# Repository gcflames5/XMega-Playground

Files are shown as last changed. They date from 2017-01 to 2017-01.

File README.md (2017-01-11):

XMega Playground
====

Overview
----
This board serves as a place where users can practice various aspects of embedded programming using an XMega(128/64/32)A4U. The first version of this board is focused heavily on testing various types of communication protocols, featuring USB, Serial, CAN, SPI, and I2C. Additionally, the board includes a pair of 7 segment displays, and 10 LEDs (4 are digital RGB LEDs) to allow a degree of output to the user. For use with these various communication protocols, this board includes an separate ADC (with pressure and temperature sensors), flash memory IC, TTL to RS-232 level shifter, CAN transciever, and two IMUs.



List of Features (version 1.0)
----
 - 2 7-segment displays (driven by shift registers)
 - 4 WS2812B digital RHB leds
 - 6 0805 LEDs
 - CAN Transciever
 - RS-232 to TTL level shifter
 - 2 IMUs: Acceleration, Magetometer
 - ADC (w/ 2.5V reference chip)
   - Temperature sensor
   - Ambient pressure sensor
 - Flash Memory
 - Current Sense Op Amp
   - Configurable load for testing

Considerations for Future Versions
----
 - Add a character LCD display for more useful output to the user
 - Break out more GPIO pins into headers
 - Expand number of 7 segment displays
 - Utilize DAC and waveform generation, include H-bridge, microphone, speaker, etc.

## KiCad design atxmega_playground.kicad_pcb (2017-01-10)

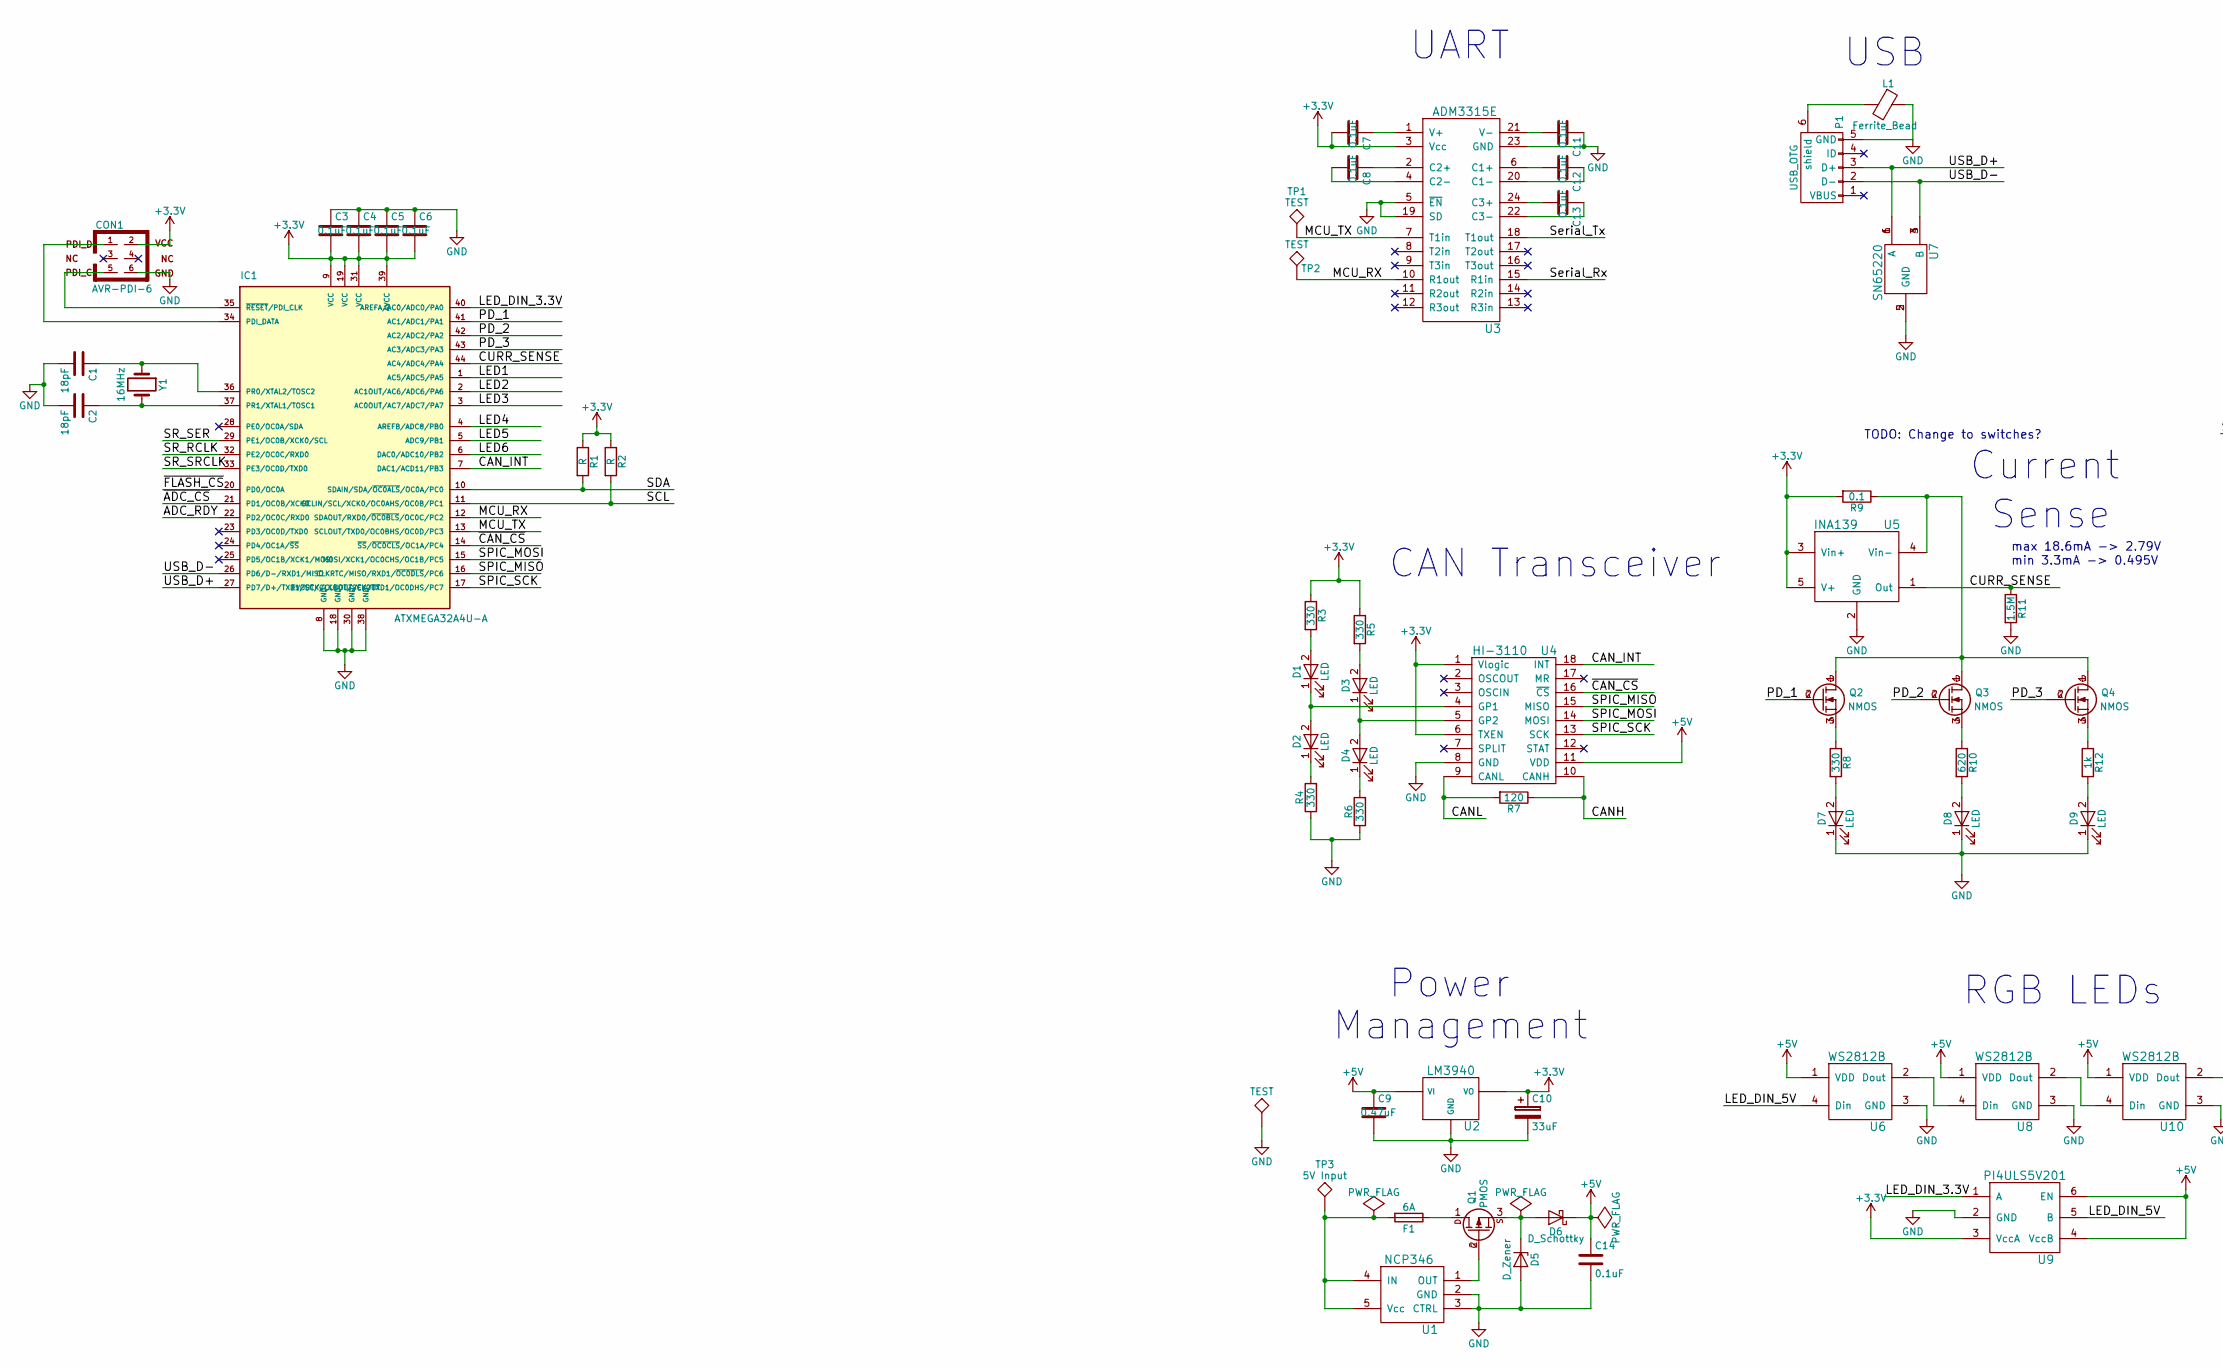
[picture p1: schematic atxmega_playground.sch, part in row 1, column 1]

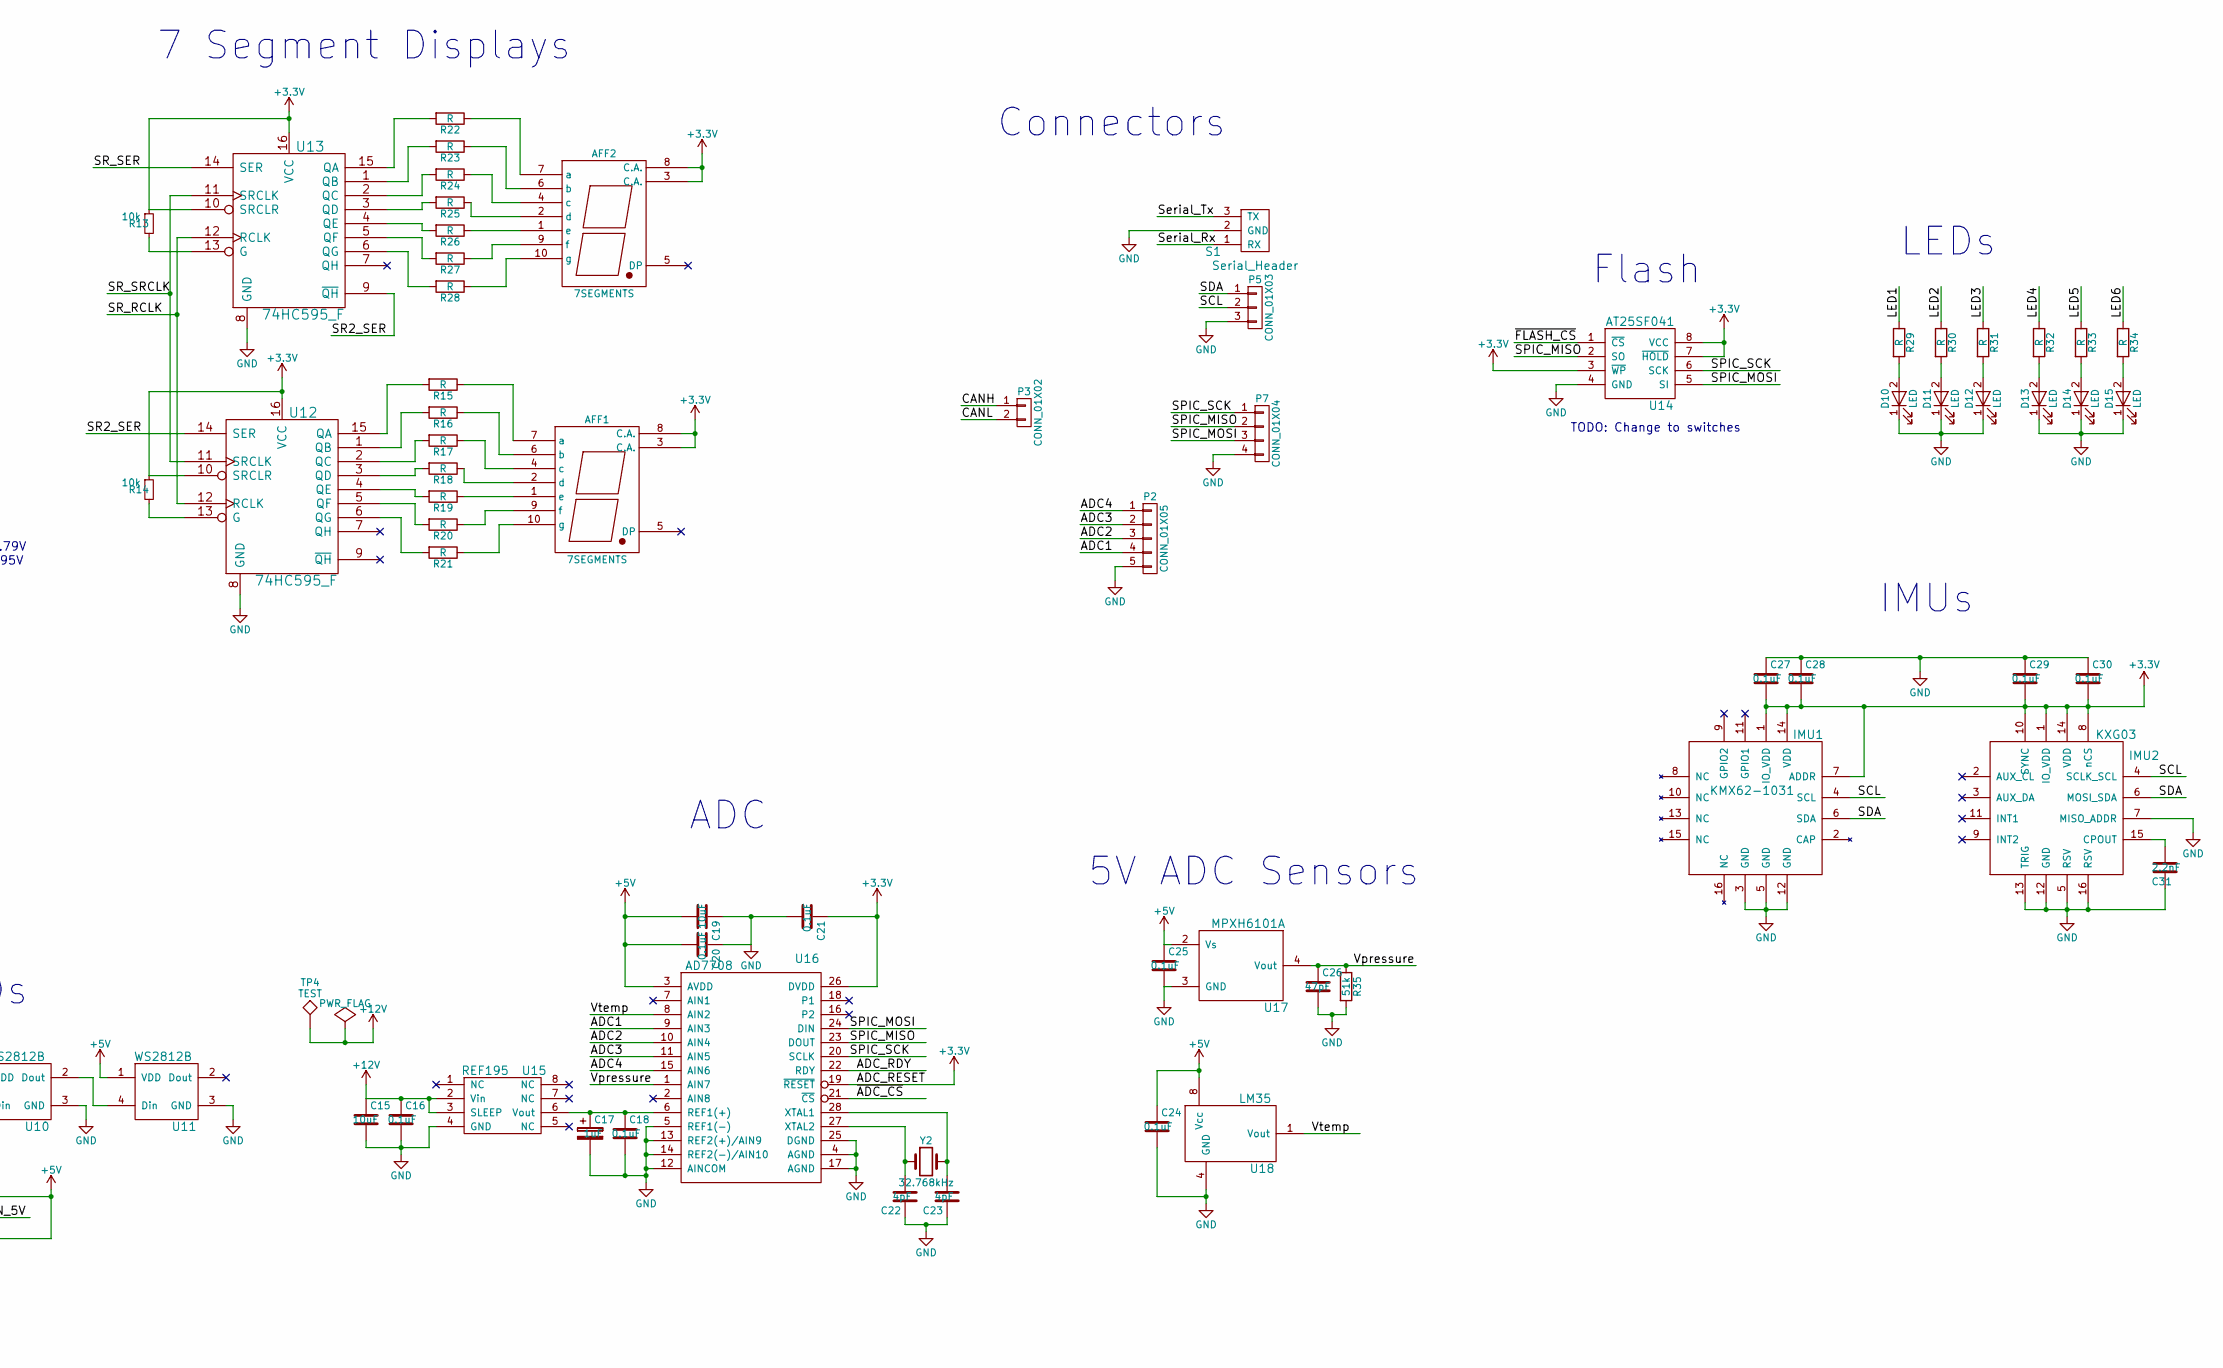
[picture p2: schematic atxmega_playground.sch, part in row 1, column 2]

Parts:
AFF1, AFF2: 7SEGMENTS; 7seg_SC56-11SRWA
C1, C2: 18pF; C_0805
C3, C4, C5, C6, C7, C8, C11, C12, C13, C14, C16, C18, C20, C21, C24, C25, C27, C28, C29, C30: 0.1uF; C_0805
C9: 0.47uF; C_0805
C10: 33uF; R_1206
C15, C19: 10uF; C_0805
C17: 1uF; R_1206
C22, C23: 4pF; C_0805
C26: 47pF; C_0805
C31: 2.2nF; C_0805
CON1: AVR-PDI-6; Pin_Header_Straight_2x03_Pitch2.54mm
D1, D2, D3, D4, D7, D8, D9, D10, D11, D12, D13, D14, D15: LED; LED_0805
D5: D_Zener; SOD-123
D6: D_Schottky; R_0805
F1: 6A; R_1206
IC1: ATXMEGA32A4U-A; TQFP-44_10x10mm_Pitch0.8mm
IMU1: KMX62-1031; KXG03_footprint
IMU2: KXG03; KXG03_footprint
L1: Ferrite_Bead; R_0805
P1: USB_OTG; USB_Mini-B
P2: CONN_01X05; Pin_Header_Straight_1x05_Pitch2.54mm
P3: CONN_01X02; Pin_Header_Straight_1x02_Pitch2.54mm
P5: CONN_01X03; Pin_Header_Straight_1x03_Pitch2.54mm
P7: CONN_01X04; Pin_Header_Straight_1x04_Pitch2.54mm
Q1: PMOS; SOT-23-3_Handsoldering
Q2, Q3, Q4: NMOS; SOT-23-3_Handsoldering
R1, R2, R15, R16, R17, R18, R19, R20, R21, R22, R23, R24, R25, R26, R27, R28, R29, R30, R31, R32, R33, R34: R; R_0805
R3, R4, R5, R6, R8: 330; R_0805
R7: 120; R_0805
R9: 0.1; R_0805
R10: 620; R_0805
R11: 1.5M; R_0805
R12: 1k; R_0805
R13, R14: 10k; R_0805
R35: 51k; R_0805
S1: Serial_Header; Pin_Header_Straight_1x03_Pitch2.54mm
TP1, TP2, TP4, TP5: TEST; TESTPOINT
TP3: 5V Input; TESTPOINT
U1: NCP346; SOT-23-5
U2: LM3940; SOT-223
U3: ADM3315E; TSSOP-24_4.4x7.8mm_Pitch0.65mm
U4: HI-3110; SOIC-18W_7.5x11.6mm_Pitch1.27mm
U5: INA139; SOT-23-5
U6, U8, U10, U11: WS2812B
U7: SN65220; SOT-23-6
U9: PI4ULS5V201; SOT-23-6
U12, U13: 74HC595_F; SOIC-16_3.9x9.9mm_Pitch1.27mm
U14: AT25SF041; SOIC-8_3.9x4.9mm_Pitch1.27mm
U15: REF195; SOIC-8_3.9x4.9mm_Pitch1.27mm
U16: AD7708; SOIC-28W_7.5x17.9mm_Pitch1.27mm
U17: MPXH6101A; SOIC-8_7.5x7.5mm_Pitch1.27mm
U18: LM35; SOIC-8_3.9x4.9mm_Pitch1.27mm
Y1: 16MHz; Crystal_HC49-U_Vertical
Y2: 32.768kHz; R_0805

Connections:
+3V3: AFF1.3 (C.A.), AFF1.8 (C.A.), AFF2.3 (C.A.), AFF2.8 (C.A.), C3.2, C4.2, C5.2, C6.2, C7.2, C10.1, C21.1, C27.2, C28.2, C29.2, C30.2, CON1.2, IC1.9 (VCC), IC1.19 (VCC), IC1.31 (VCC), IC1.39 (AVCC), IMU1.1 (IO_VDD), IMU1.7 (ADDR), IMU1.14 (VDD), IMU2.1 (IO_VDD), IMU2.8 (nCS), IMU2.10 (SYNC), IMU2.14 (VDD), R1.1, R2.1, R3.1, R5.1, R9.2, R13.1, R14.1, U2.3 (VO), U3.3 (Vcc), U4.1 (Vlogic), U4.6 (TXEN), U5.3 (Vin+), U5.5 (V+), U9.3 (VccA), U12.10 (SRCLR), U12.16 (VCC), U13.10 (SRCLR), U13.16 (VCC), U14.3 (~WP), U14.7 (~HOLD), U14.8 (VCC), U16.19 (~RESET), U16.26 (DVDD)
+5V: C9.1, C14.1, C19.2, C20.2, C24.1, C25.1, D6.1 (K), U2.1 (VI), U4.11 (VDD), U6.1 (VDD), U8.1 (VDD), U9.4 (VccB), U9.6 (EN), U10.1 (VDD), U11.1 (VDD), U16.3 (AVDD), U17.2 (Vs), U18.8 (Vcc)
+12V: C15.1, C16.1, TP4.1, U15.2 (Vin), U15.3 (SLEEP)
/ADC1: P2.4, U16.9 (AIN3)
/ADC2: P2.3, U16.10 (AIN4)
/ADC3: P2.2, U16.11 (AIN5)
/ADC4: P2.1, U16.15 (AIN6)
/ADC_RDY: IC1.22 (PD2/OC0C/RXD0), U16.22 (RDY)
/CANH: P3.1, R7.1, U4.10 (CANH)
/CANL: P3.2, R7.2, U4.9 (CANL)
/CAN_INT: IC1.7 (DAC1/ACD11/PB3), U4.18 (INT)
/CURR_SENSE: IC1.44 (AC4/ADC4/PA4), R11.1, U5.1 (Out)
/LED1: IC1.1 (AC5/ADC5/PA5), R29.1
/LED2: IC1.2 (AC1OUT/AC6/ADC6/PA6), R30.1
/LED3: IC1.3 (AC0OUT/AC7/ADC7/PA7), R31.1
/LED4: IC1.4 (AREFB/ADC8/PB0), R32.1
/LED5: IC1.5 (ADC9/PB1), R33.1
/LED6: IC1.6 (DAC0/ADC10/PB2), R34.1
/LED_DIN_3.3V: IC1.40 (AREFA/AC0/ADC0/PA0), U9.1 (A)
/LED_DIN_5V: U6.4 (Din), U9.5 (B)
/MCU_RX: IC1.12 (SDAOUT/RXD0/~OC0BLS~/OC0C/PC2), TP2.1, U3.10 (R1out)
/MCU_TX: IC1.13 (SCLOUT/TXD0/OC0BHS/OC0D/PC3), TP1.1, U3.7 (T1in)
/PD_1: IC1.41 (AC1/ADC1/PA1), Q2.2 (G)
/PD_2: IC1.42 (AC2/ADC2/PA2), Q3.2 (G)
/PD_3: IC1.43 (AC3/ADC3/PA3), Q4.2 (G)
/SCL: IC1.11 (SCLIN/SCL/XCK0/OC0AHS/OC0B/PC1), IMU1.4 (SCL), IMU2.4 (SCLK_SCL), P5.2, R2.2
/SDA: IC1.10 (SDAIN/SDA/~OC0ALS~/OC0A/PC0), IMU1.6 (SDA), IMU2.6 (MOSI_SDA), P5.1, R1.2
/SPIC_MISO: IC1.16 (CLKRTC/MISO/RXD1/~OC0DLS~/PC6), P7.2, U4.15 (MISO), U14.2 (SO), U16.23 (DOUT)
/SPIC_MOSI: IC1.15 (MOSI/XCK1/OC0CHS/OC1B/PC5), P7.3, U4.14 (MOSI), U14.5 (SI), U16.24 (DIN)
/SPIC_SCK: IC1.17 (EVOUT/CLKOUT/SCK/TXD1/OC0DHS/PC7), P7.1, U4.13 (SCK), U14.6 (SCK), U16.20 (SCLK)
/SR2_SER: U12.14 (SER), U13.9 (~QH)
/SR_RCLK: IC1.32 (PE2/OC0C/RXD0), U12.12 (RCLK), U13.12 (RCLK)
/SR_SER: IC1.29 (PE1/OC0B/XCK0/SCL), U13.14 (SER)
/SR_SRCLK: IC1.33 (PE3/OC0D/TXD0), U12.11 (SRCLK), U13.11 (SRCLK)
/Serial_Rx: S1.1 (RX), U3.15 (R1in)
/Serial_Tx: S1.3 (TX), U3.18 (T1out)
/USB_D+: IC1.27 (PD7/D+/TXD1/SCK/CLKOUT/EVOUT), P1.3 (D+), U7.1 (A), U7.6 (A)
/USB_D-: IC1.26 (PD6/D-/RXD1/MISO), P1.2 (D-), U7.3 (B), U7.4 (B)
/Vpressure: C26.1, R35.1, U16.1 (AIN7), U17.4 (Vout)
/Vtemp: U16.8 (AIN2), U18.1 (Vout)
/~ADC_CS: IC1.21 (PD1/OC0B/XCK0), U16.21 (~CS)
/~CAN_CS: IC1.14 (~SS~/~OC0CLS~/OC1A/PC4), U4.16 (~CS)
/~FLASH_CS: IC1.20 (PD0/OC0A), U14.1 (~CS)
GND: C1.2, C2.2, C3.1, C4.1, C5.1, C6.1, C9.2, C10.2, C11.1, C14.2, C15.2, C16.2, C17.2, C18.2, C19.1, C20.1, C21.2, C22.1, C23.1, C24.2, C25.2, C26.2, C27.1, C28.1, C29.1, C30.1, C31.2, CON1.6, D5.2 (A), D7.1 (K), D8.1 (K), D9.1 (K), D10.1 (K), D11.1 (K), D12.1 (K), D13.1 (K), D14.1 (K), D15.1 (K), IC1.8 (GND), IC1.18 (GND), IC1.30 (GND), IC1.38 (GND), IMU1.3 (GND), IMU1.5 (GND), IMU1.12 (GND), IMU2.5 (RSV), IMU2.7 (MISO_ADDR), IMU2.12 (GND), IMU2.13 (TRIG), IMU2.16 (RSV), L1.1, P1.5 (GND), P2.5, P5.3, P7.4, R4.1, R6.1, R11.2, R35.2, S1.2 (GND), TP5.1, U1.2 (GND), U1.3 (CTRL), U2.2 (GND), U2.4 (GND), U3.5 (~EN), U3.19 (SD), U3.23 (GND), U4.8 (GND), U5.2 (GND), U6.3 (GND), U7.2 (GND), U7.5 (GND), U8.3 (GND), U9.2 (GND), U10.3 (GND), U11.3 (GND), U12.8 (GND), U13.8 (GND), U14.4 (GND), U15.4 (GND), U16.4 (AGND), U16.5 (REF1(-)), U16.12 (AINCOM), U16.13 (REF2(+)/AIN9), U16.14 (REF2(-)/AIN10), U16.17 (AGND), U16.25 (DGND), U17.3 (GND), U18.4 (GND)
unnamed: AFF1.1 (e), R19.1
unnamed: AFF1.2 (d), R18.1
unnamed: AFF1.4 (c), R17.1
unnamed: AFF1.6 (b), R16.1
unnamed: AFF1.7 (a), R15.1
unnamed: AFF1.9 (f), R20.1
unnamed: AFF1.10 (g), R21.1
unnamed: AFF2.1 (e), R26.1
unnamed: AFF2.2 (d), R25.1
unnamed: AFF2.4 (c), R24.1
unnamed: AFF2.6 (b), R23.1
unnamed: AFF2.7 (a), R22.1
unnamed: AFF2.9 (f), R27.1
unnamed: AFF2.10 (g), R28.1
unnamed: C1.1, IC1.36 (PR0/XTAL2/TOSC2), Y1.1
unnamed: C2.1, IC1.37 (PR1/XTAL1/TOSC1), Y1.2
unnamed: C7.1, U3.1 (V+)
unnamed: C8.1, U3.2 (C2+)
unnamed: C8.2, U3.4 (C2-)
unnamed: C11.2, U3.21 (V-)
unnamed: C12.1, U3.20 (C1-)
unnamed: C12.2, U3.6 (C1+)
unnamed: C13.1, U3.22 (C3-)
unnamed: C13.2, U3.24 (C3+)
unnamed: C17.1, C18.1, U15.6 (Vout), U16.6 (REF1(+))
unnamed: C22.2, U16.27 (XTAL2), Y2.1
unnamed: C23.2, U16.28 (XTAL1), Y2.2
unnamed: C31.1, IMU2.15 (CPOUT)
unnamed: CON1.1, IC1.34 (PDI_DATA)
unnamed: CON1.5, IC1.35 (~RESET~/PDI_CLK)
unnamed: D1.1 (K), D2.2 (A), U4.4 (GP1)
unnamed: D1.2 (A), R3.2
unnamed: D2.1 (K), R4.2
unnamed: D3.1 (K), D4.2 (A), U4.5 (GP2)
unnamed: D3.2 (A), R5.2
unnamed: D4.1 (K), R6.2
unnamed: D5.1 (K), D6.2 (A), Q1.3 (S)
unnamed: D7.2 (A), R8.2
unnamed: D8.2 (A), R10.2
unnamed: D9.2 (A), R12.2
unnamed: D10.2 (A), R29.2
unnamed: D11.2 (A), R30.2
unnamed: D12.2 (A), R31.2
unnamed: D13.2 (A), R32.2
unnamed: D14.2 (A), R33.2
unnamed: D15.2 (A), R34.2
unnamed: F1.1, Q1.1 (D)
unnamed: F1.2, TP3.1, U1.4 (IN), U1.5 (Vcc)
unnamed: L1.2, P1.6 (shield)
unnamed: Q1.2 (G), U1.1 (OUT)
unnamed: Q2.1 (D), Q3.1 (D), Q4.1 (D), R9.1, U5.4 (Vin-)
unnamed: Q2.3 (S), R8.1
unnamed: Q3.3 (S), R10.1
unnamed: Q4.3 (S), R12.1
unnamed: R13.2, U13.13 (G)
unnamed: R14.2, U12.13 (G)
unnamed: R15.2, U12.15 (QA)
unnamed: R16.2, U12.1 (QB)
unnamed: R17.2, U12.2 (QC)
unnamed: R18.2, U12.3 (QD)
unnamed: R19.2, U12.4 (QE)
unnamed: R20.2, U12.5 (QF)
unnamed: R21.2, U12.6 (QG)
unnamed: R22.2, U13.15 (QA)
unnamed: R23.2, U13.1 (QB)
unnamed: R24.2, U13.2 (QC)
unnamed: R25.2, U13.3 (QD)
unnamed: R26.2, U13.4 (QE)
unnamed: R27.2, U13.5 (QF)
unnamed: R28.2, U13.6 (QG)
unnamed: U6.2 (Dout), U8.4 (Din)
unnamed: U10.2 (Dout), U11.4 (Din)
unnamed: U8.2 (Dout), U10.4 (Din)

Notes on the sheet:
UART
CAN Transceiver
USB
Current
Sense
max 18.6mA -> 2.79V
min 3.3mA -> 0.495V
TODO: Change to switches?
7 Segment Displays
TODO: Change to switches
Flash
Power
Management
RGB LEDs
LEDs
Connectors
ADC
5V ADC Sensors
IMUs

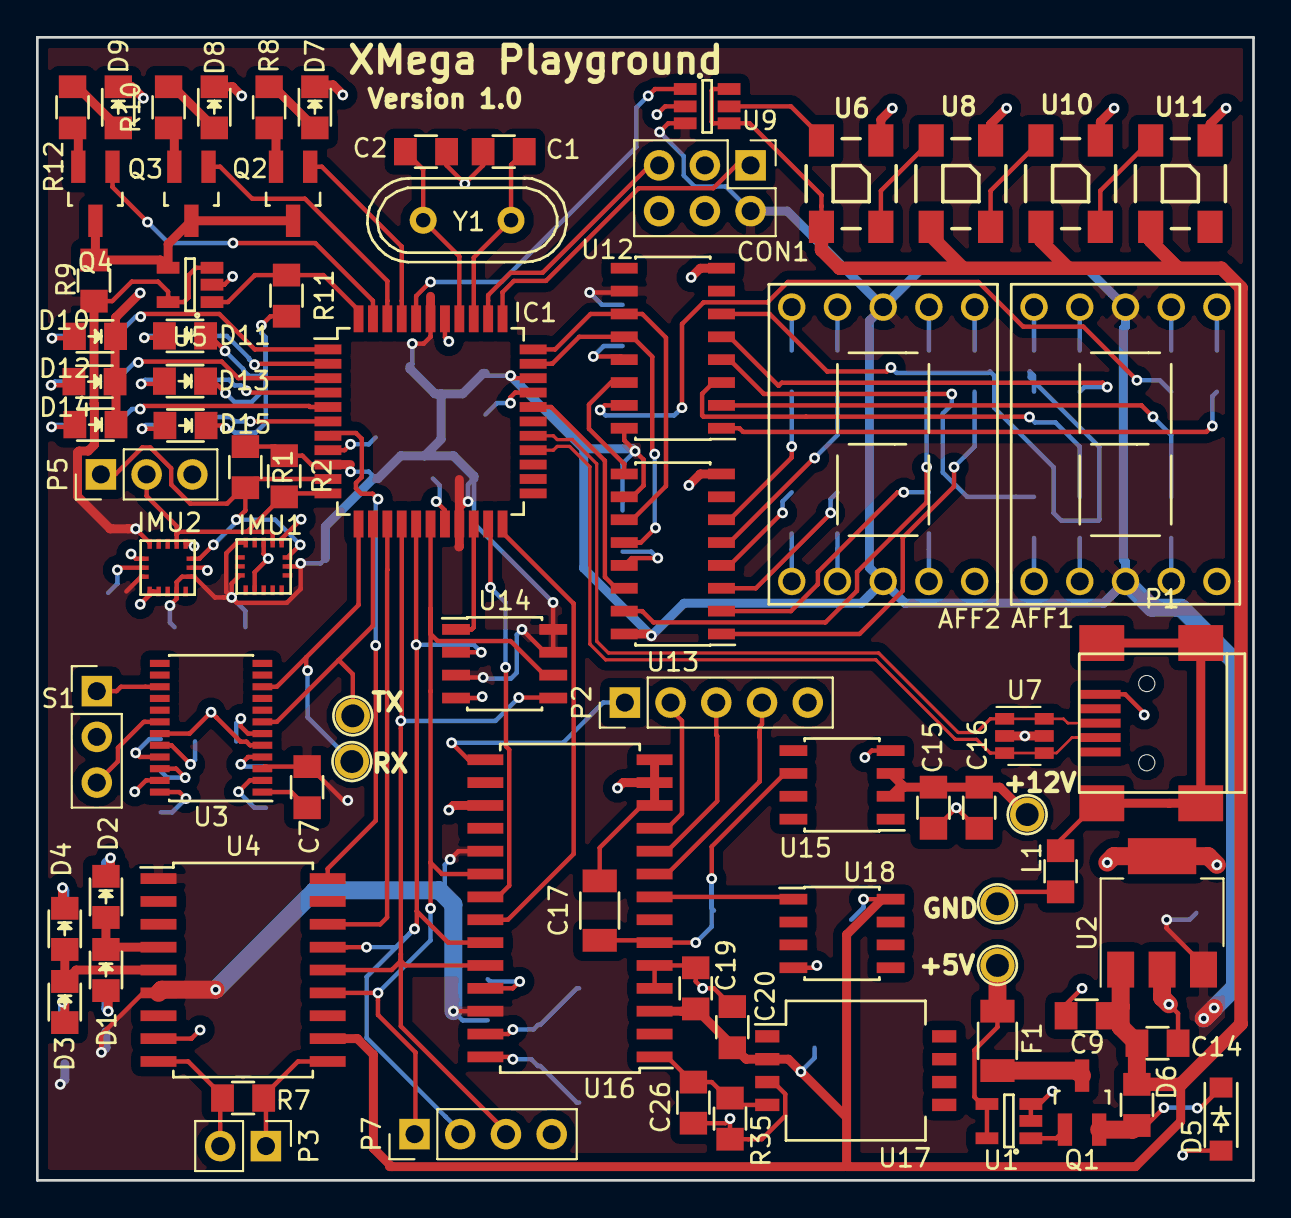
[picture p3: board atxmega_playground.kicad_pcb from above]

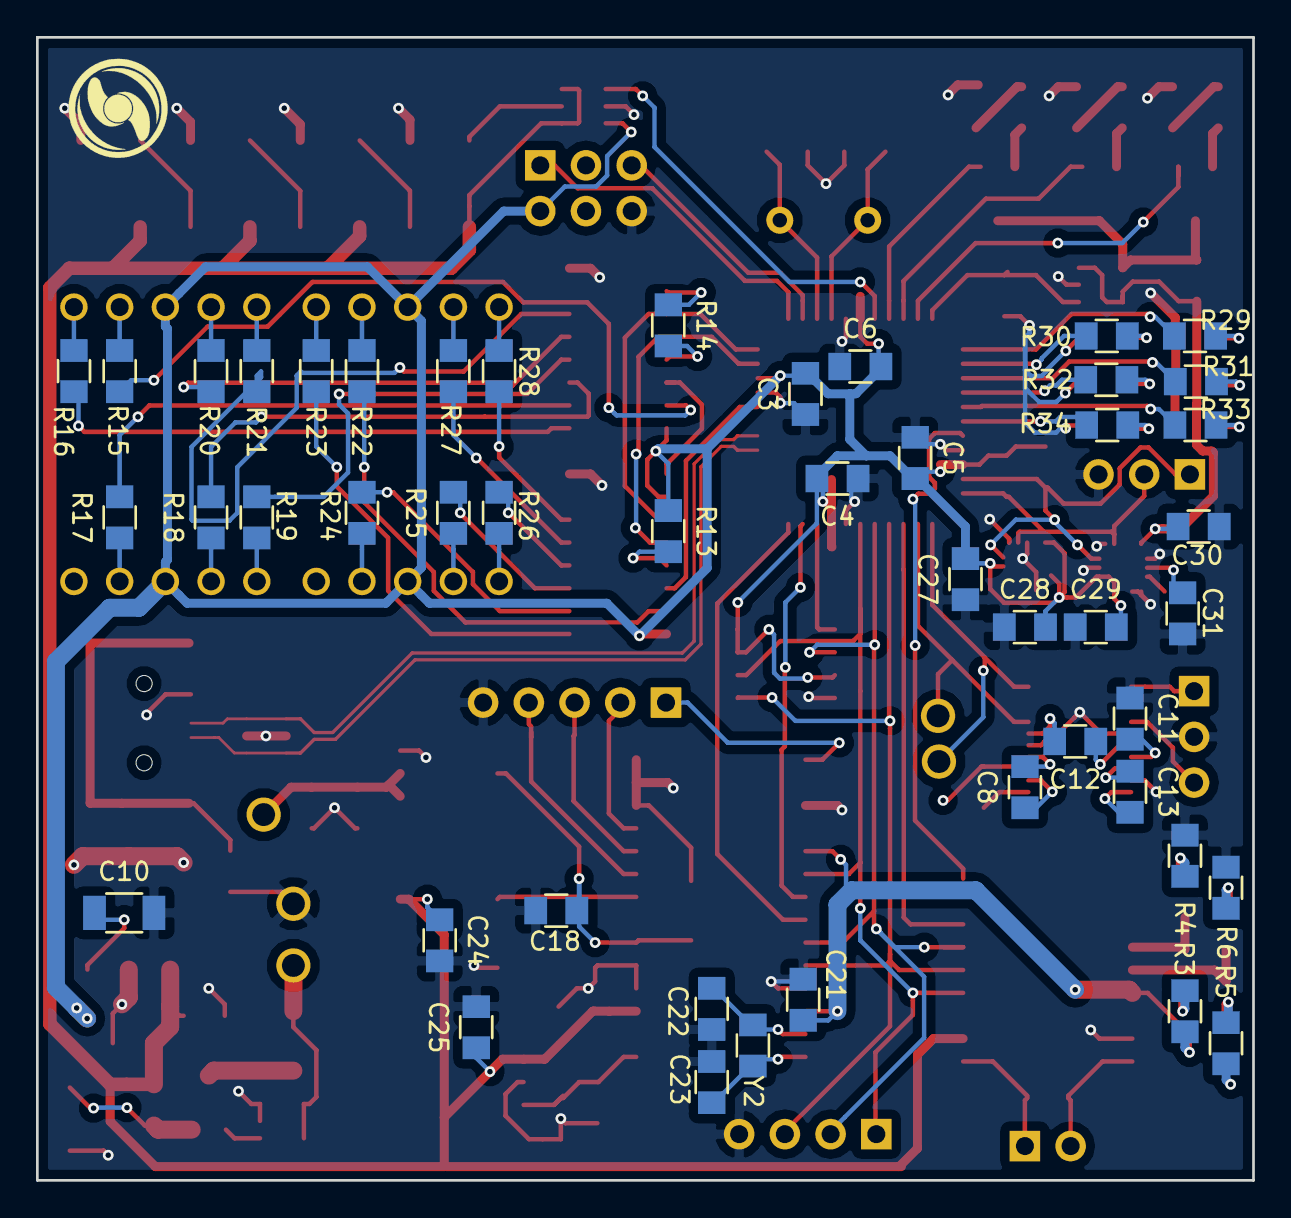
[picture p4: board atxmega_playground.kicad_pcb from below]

Board: 2 copper layers, 67.6 x 63.5 mm, 124 parts (47 on the bottom side), 117 nets.

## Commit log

2017-01-06 Initial Commit: empty project and readme
    [atxmega_playground.kicad_pcb, atxmega_playground.sch]
2017-01-07 Add 3.3V ttl to +/- 10V RS-232 level shifter
2017-01-07 Add HI-3110 CAN Transceiver
    [atxmega_playground.sch]
2017-01-07 Add USB and Current Sense
    [atxmega_playground.sch]
2017-01-07 Fix current sense voltage calculations
    [atxmega_playground.sch]
2017-01-07 Add 74HC595 shift register and LEDs
    [atxmega_playground.sch]
2017-01-07 Drive 2 7-seg displays via shift registers, add flash memory
    [atxmega_playground.sch]
2017-01-08 Add a few i2c sensors, power management circuitry, and digital RGB LEDs
    [atxmega_playground.sch]
2017-01-08 Fill out MCU pins, add LEDs, (and digital pot maybe?)
    [atxmega_playground.sch]
2017-01-08 Add breakout connectors
    [atxmega_playground.sch]
2017-01-08 Begin assigning footprints
    [atxmega_playground.sch]
2017-01-08 More footprints, beginning stages of layout
    [atxmega_playground.sch]
2017-01-09 Add GPIO's ADC and 5V sensors, 7seg display footprint, and HIM's IMU's
    [atxmega_playground.kicad_pcb, atxmega_playground.sch]
2017-01-10 Basic layout, component positions mostly final
    [_saved_atxmega_playground.sch, atxmega_playground.kicad_pcb, atxmega_playground.sch]
2017-01-10 Initial layout complete, no DRC errors or unconnected tracks
    [_saved_atxmega_playground.sch, atxmega_playground.kicad_pcb, atxmega_playground.sch]
2017-01-10 Move refdes text
    [atxmega_playground.kicad_pcb]
2017-01-10 Final touches
    [atxmega_playground.kicad_pcb]
2017-01-10 First revision, finalized!
    [atxmega_playground.kicad_pcb, atxmega_playground.sch]
